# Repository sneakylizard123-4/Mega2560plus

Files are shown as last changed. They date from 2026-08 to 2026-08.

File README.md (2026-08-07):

# Mega 2560+

Mega 2560+ is an upgraded version of the Arduino Mega 2560. It keeps the same form factor and pinout as the original so it still drops into every Mega shield, but it adds an onboard sensor suite and an ESP32-S3 co-processor for WiFi, Bluetooth, and sensor reading.

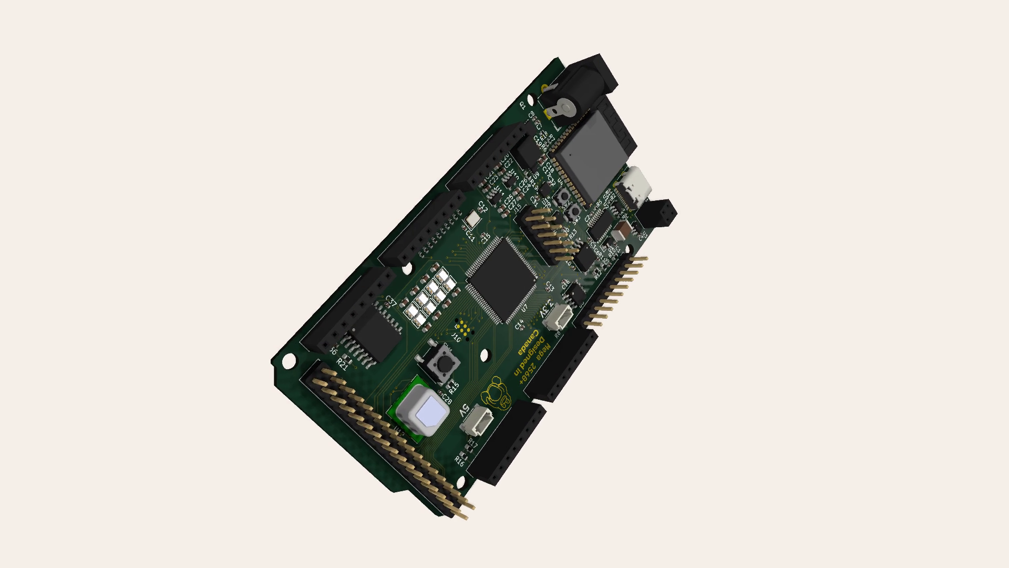
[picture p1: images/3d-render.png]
3D render


## Why I made it

I kept reaching for a Mega plus a pile of breakout boards — a CO2 sensor here, an IMU there, a WiFi module taped on somewhere. It was messy and fragile. I wanted a single board I can just drop into a project that already knows the room around it: temperature, humidity, air quality, CO2, and motion. And since everything talks to the network these days, an ESP32-S3 handles the WiFi/Bluetooth so the Mega can focus on running the actual project.

## Key Features

- ATmega2560-16A main MCU (same chip as the original Mega)
- ESP32-S3-WROOM-1U co-processor with 16MB flash / 8MB PSRAM for WiFi and Bluetooth
- Onboard sensor suite:
  - SCD41 CO2 sensor
  - BME680 temp / humidity / pressure / air quality
  - LSM6DSL 6-axis IMU
- DS3231M RTC with battery backup (CR2032)
- FM24C64C FRAM and W25Q128JVS SPI flash for storage
- USB-C with FT231XS USB-UART and ESD protection
- WS2812B-2020 addressable status LEDs
- TPS62163 buck + TLV75733 LDO power section, barrel jack or battery input with reverse polarity protection
- Drop-in Mega pinout — compatible with existing Mega shields

## Images

### PCB Layout

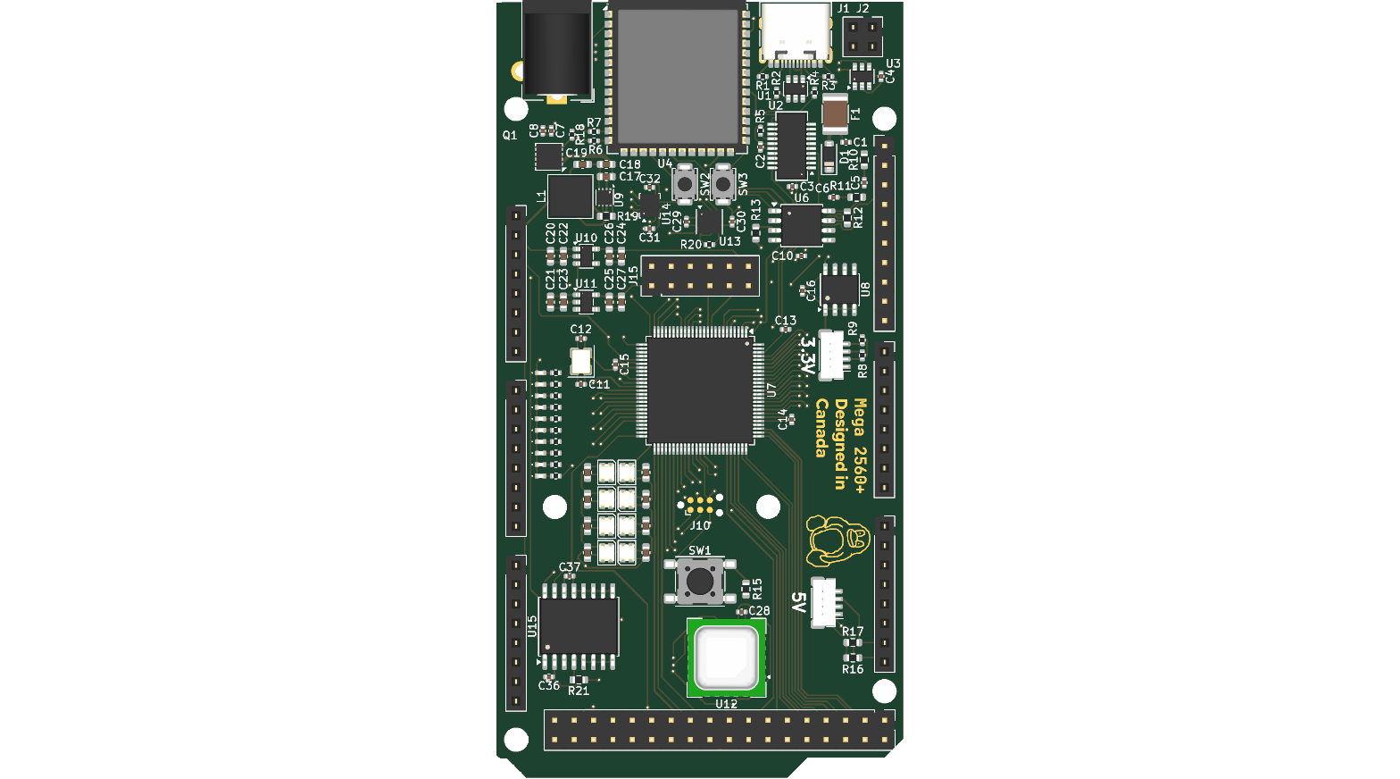
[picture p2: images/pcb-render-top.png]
PCB render


### Schematic

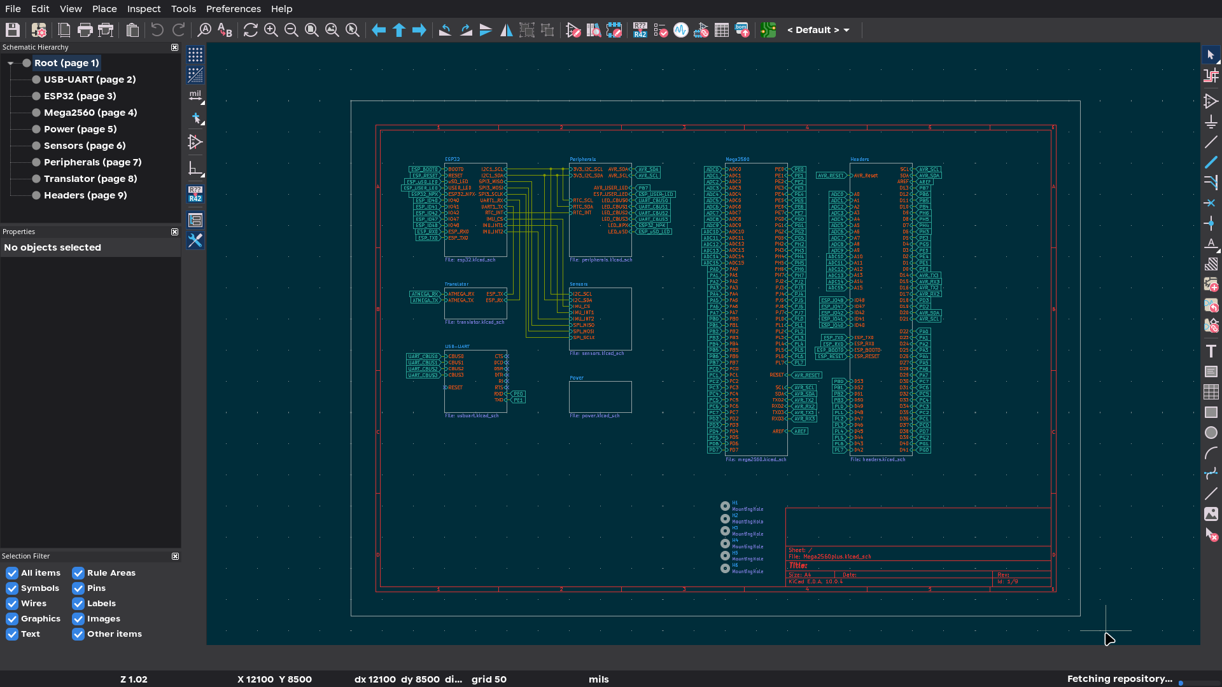
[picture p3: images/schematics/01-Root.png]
Root schematic


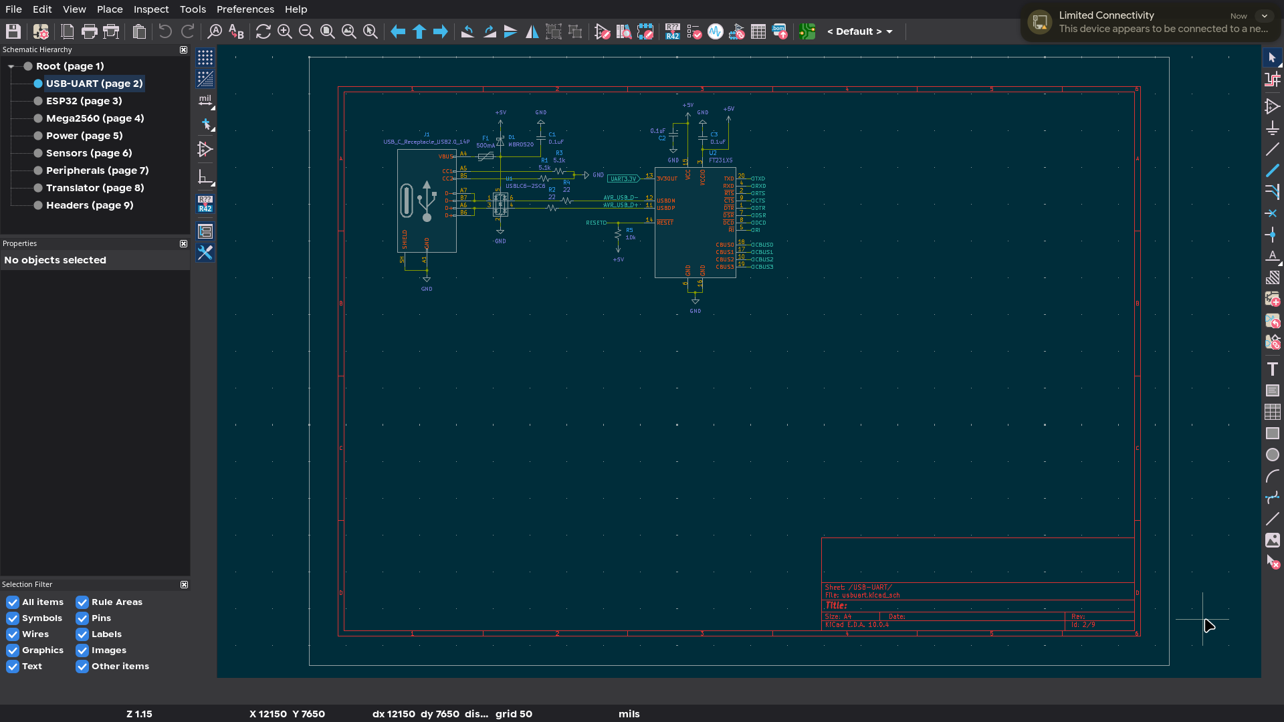
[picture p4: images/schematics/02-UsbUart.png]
USB-UART

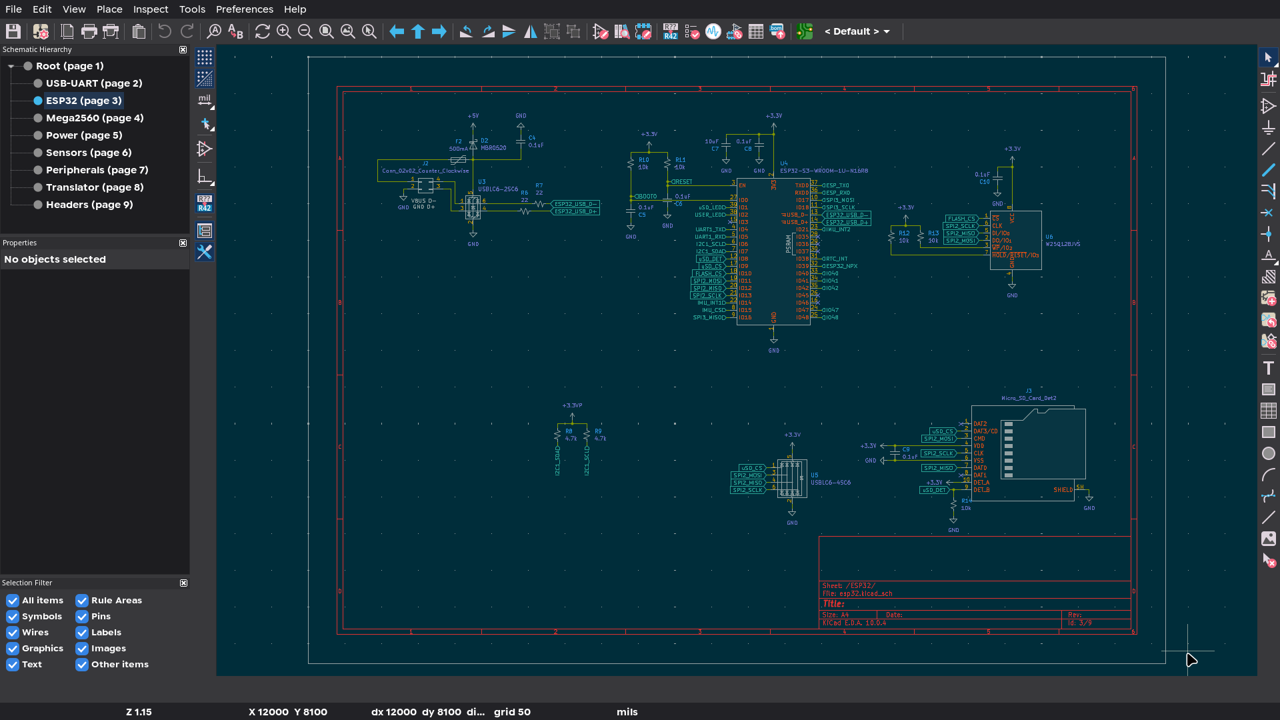
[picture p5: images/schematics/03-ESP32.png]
ESP32

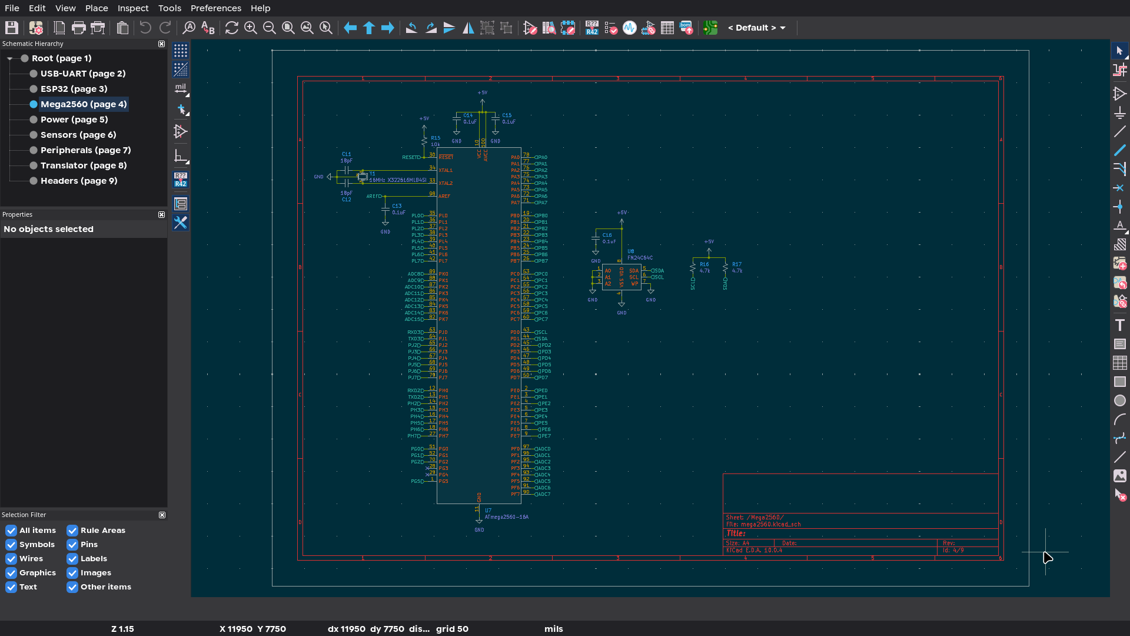
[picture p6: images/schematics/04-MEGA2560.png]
Mega 2560

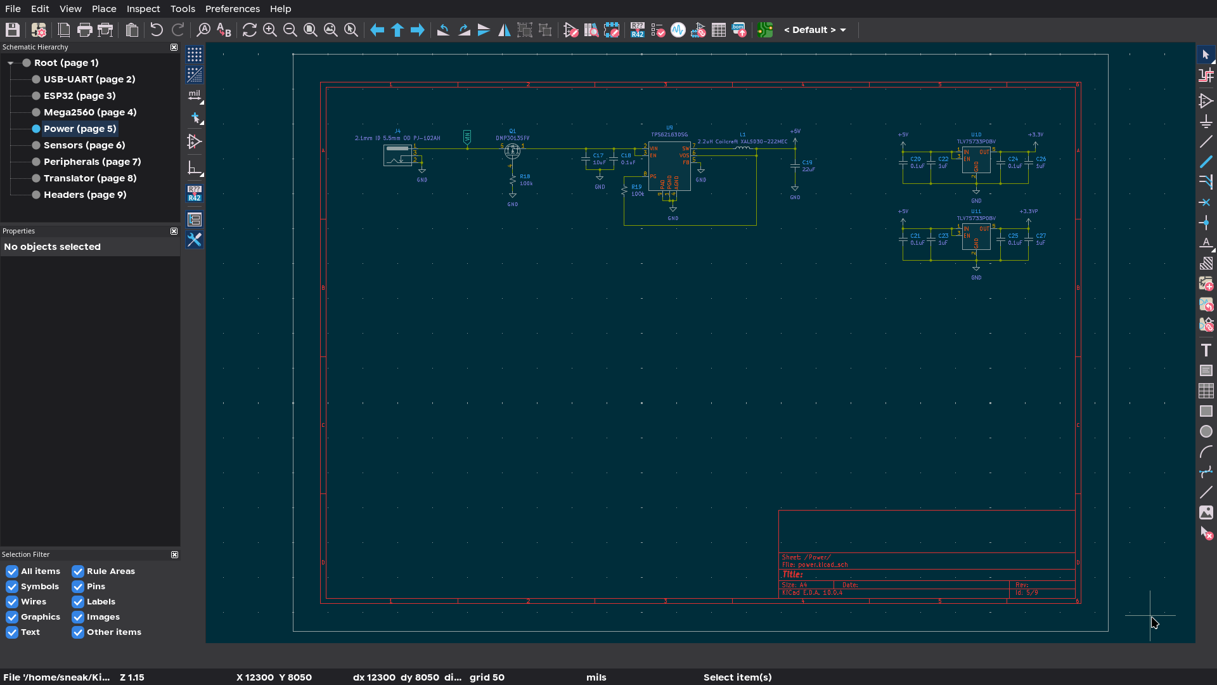
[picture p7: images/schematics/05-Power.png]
Power

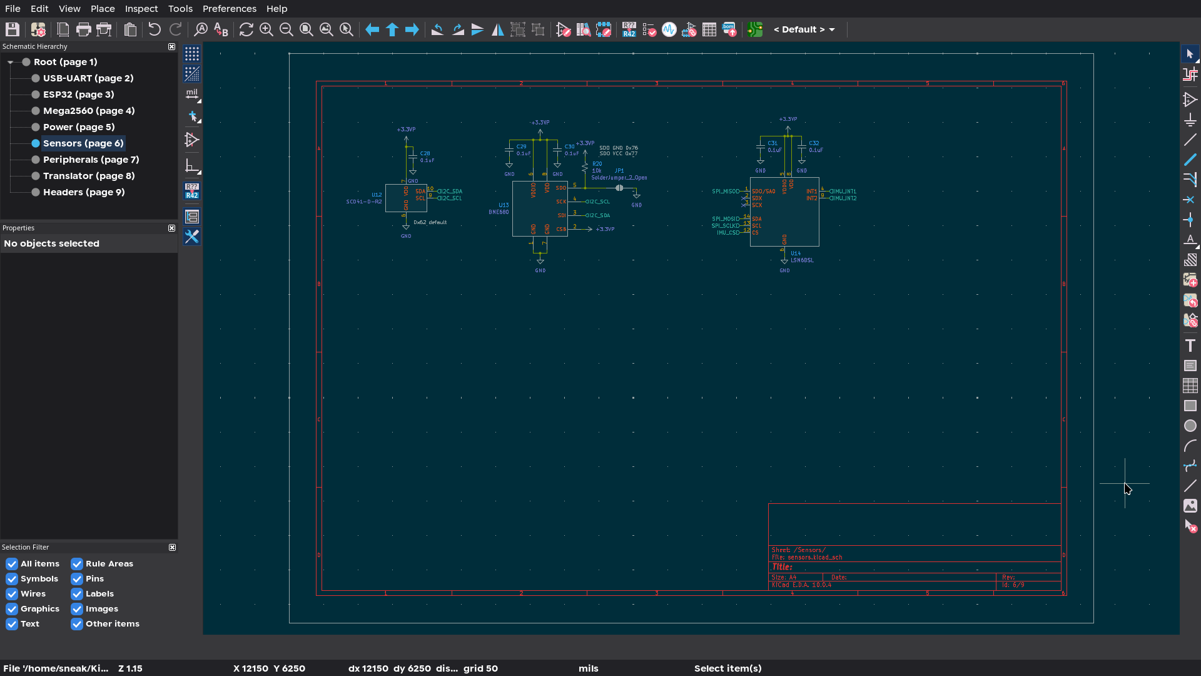
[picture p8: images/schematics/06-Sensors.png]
Sensors

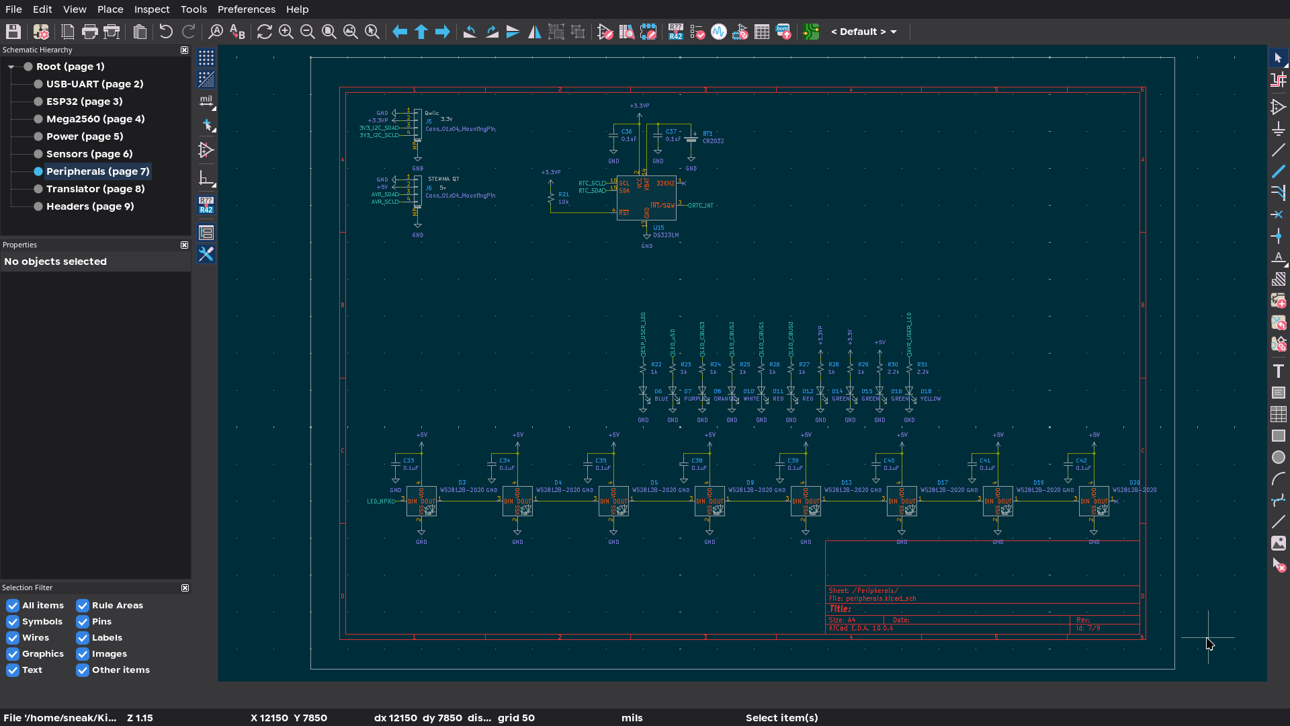
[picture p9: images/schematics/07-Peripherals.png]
Peripherals

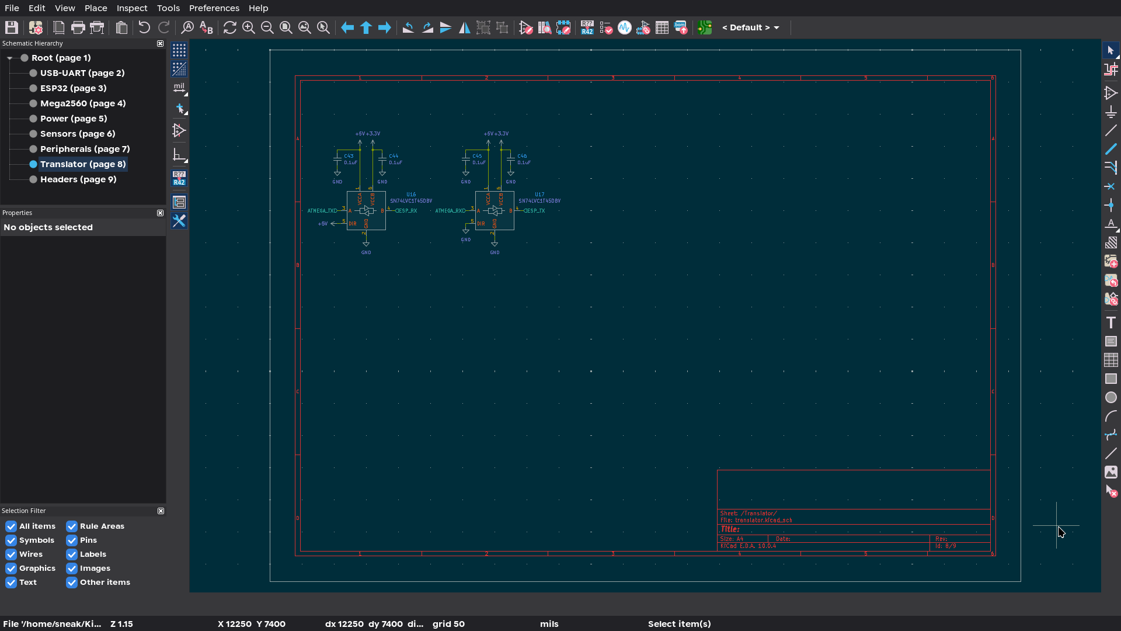
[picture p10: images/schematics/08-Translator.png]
Translator

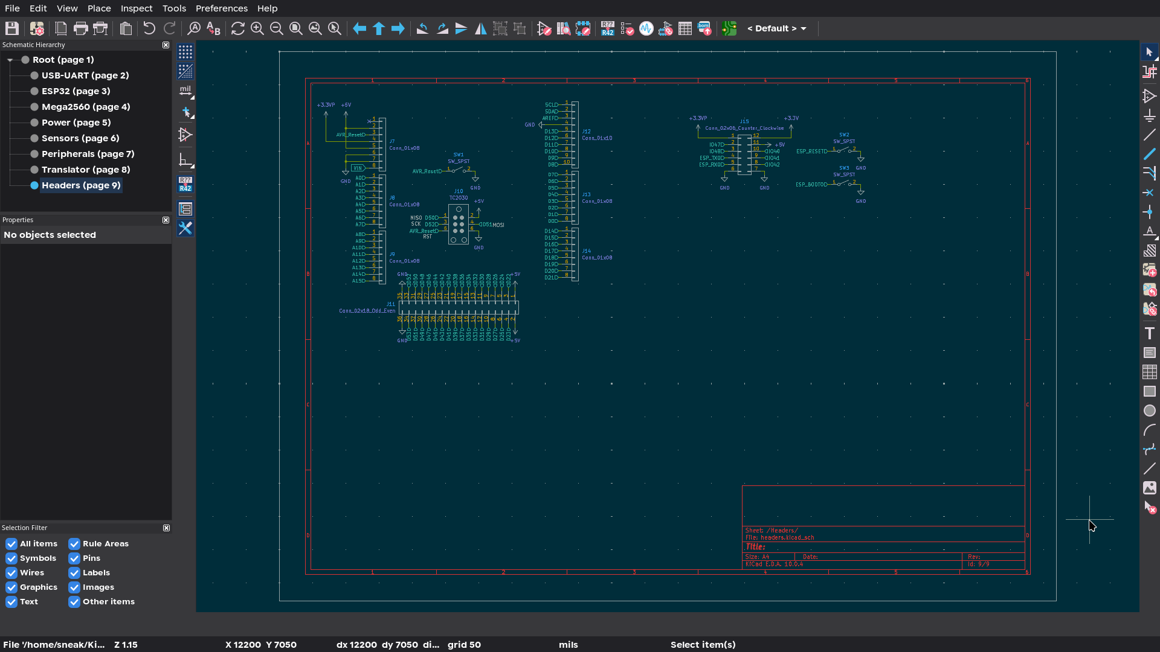
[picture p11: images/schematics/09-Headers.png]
Headers


## How to use

It's an Arduino Mega with extras. Flash it like any Mega — the ATmega2560 programs over the USB-C port. The sensors and RTC sit on the I2C bus (SCL/SDA at pins 20/21) with different addresses:

| Device | I2C Address |
|---|---|
| BME680 | 0x76 |
| SCD41 | 0x62 |
| LSM6DSL  | 0x6A |
| DS3231M  | 0x68 |

The ESP32-S3 connects to the Mega over UART (Serial1) through level translators, and handles WiFi/Bluetooth. It also reads the sensors over the same I2C bus.

## Assembly

1. Solder all SMD components, starting with the smallest packages (0402) and working up.
2. Solder the through-hole headers, connectors, and the USB-C receptacle.
3. Insert the CR2032 coin cell for RTC backup.
4. Power via USB-C or the barrel jack.

## Bill of Materials

A machine-generated `BOM.csv` lives in the repo root. Full list:

| Designators | Value | Package | Qty |
|---|---|---|-----|
| BT1 | CR2032 | Coin cell holder | 1 |
| C1-C6,C8,C10,C13-C16,C28-C32,C36,C37 | 0.1uF | 0402 | 19  |
| C7 | 10uF | 0402 | 1 |
| C9,C43-C46 | 0.1uF | 0805 | 5 |
| C11,C12 | 18pF | 0402 | 2 |
| C17 | 10uF | 0603 | 1 |
| C18,C20,C21,C24,C25,C33-C35,C38-C42 | 0.1uF | 0603 | 13  |
| C19 | 22uF | 0603 | 1 |
| C22,C23,C26,C27 | 1uF | 0603 | 4 |
| D1,D2 | MBR0520 | SOD-123 | 2 |
| D3-D5,D9,D13,D17,D19,D20 | WS2812B-2020 | PLCC-4 2.0x2.0mm | 8 |
| D6-D11,D14-D18 | Status LEDs | 0402 | 9 |
| F1,F2 | 500mA polyfuse | 1812 | 2 |
| J1 | USB-C receptacle | HRO TYPE-C-31-M-12 | 1 |
| J2 | 2x02 header | PinSocket 2.54mm | 1 |
| J3 | microSD slot | Hirose DM3D-SF | 1 |
| J4 | Barrel jack | PJ-102AH | 1 |
| J5,J6 | 1x04 JST-SH | JST SH BM04B-SRSS-TB | 2 |
| J7-J9,J13,J14 | 1x08 header | PinSocket 2.54mm | 5 |
| J11 | 2x18 header | PinHeader 2.54mm | 1 |
| J12 | 1x10 header | PinHeader 2.54mm | 1 |
| J15 | 2x06 header | PinHeader 2.54mm | 1 |
| L1 | 2.2uH | Coilcraft XAL5030 | 1 |
| Q1 | DMP3013SFV | PowerDI3333-8 | 1 |
| R1,R3 | 5.1k | 0402 | 2 |
| R2,R4,R6,R7 | 22 | 0402 | 4 |
| R5,R20 | 10k | 0402 | 2 |
| R8,R9 | 4.7k | 0402 | 2 |
| R10-R13,R15,R21 | 10k | 0603 | 6 |
| R14 | 10k | 0805 | 1 |
| R16,R17 | 4.7k | 0603 | 2 |
| R18,R19 | 100k | 0402 / 0603 | 2 |
| R22-R29 | 1k | 0402 | 8 |
| R30,R31 | 2.2k | 0402 | 2 |
| SW1 | Reset switch | PTS645Sx | 1 |
| SW2,SW3 | Buttons | TS-1088 | 2 |
| U1,U3,U5 | USBLC6 ESD protection | SOT-23-6 | 3 |
| U2 | FT231XS | SSOP-20 | 1 |
| U4 | ESP32-S3-WROOM-1U-N16R8 | ESP32-S3 module | 1 |
| U6 | W25Q128JVS | SOIC-8 | 1 |
| U7 | ATmega2560-16A | TQFP-100 | 1 |
| U8 | FM24C64C | SOIC-8 | 1 |
| U9 | TPS62163DSG | WSON-8 | 1 |
| U10,U11 | TLV75733PDBV | SOT-23-5 | 2 |
| U12 | SCD41-D-R2 | Sensirion SCD4x | 1 |
| U13 | BME680 | LGA-8 | 1 |
| U14 | LSM6DSL | LGA-14 | 1 |
| U15 | DS3231M | SOIC-16W | 1 |
| U16,U17 | SN74LVC1T45DBV | SOT-23-6 | 2 |
| Y1 | 16MHz crystal | 3225-4Pin | 1 |

**Total cost: TBD**

## Firmware

Source lives in [firmware/](firmware/) as a PlatformIO project with two environments:

| Env | Target | What it does |
|-----|---|---|
| `mega2560` | ATmega2560-16A | USB-UART (FT231XS), FM24C64C FRAM on I2C, Serial3 link to the ESP32 |
| `esp32s3` | ESP32-S3-WROOM-1U | Sensor reading (SCD41, BME680, LSM6DSL, DS3231M), SPI flash, NeoPixel status LEDs, WiFi/BT-ready |

Build with `pio run -e mega2560` and `pio run -e esp32s3`. The ESP32-S3 co-processor handles the sensors over its I2C1/SPI3 buses; the Mega keeps standard Arduino compatibility. See [firmware/README.md](firmware/README.md) for the full pin map.

## Known Issues

- None yet — board hasn't been fabbed. Expect some after the first build.

## Credits

- KiCad project files: [kicad/](kicad/)
- 3D models: Sensirion (SCD41), plus the WS2812B model referenced in the project

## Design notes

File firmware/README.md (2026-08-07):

# Mega 2560+ Firmware

PlatformIO firmware for the Mega 2560+ board. The board has two MCUs, each with its own environment:

| MCU | Env | Role |
|-----|-----|---|
| ATmega2560-16A | `mega2560` | Main MCU, drop-in Mega compatible. USB-UART via FT231XS, FM24C64C FRAM on I2C. |
| ESP32-S3-WROOM-1U-N16R8 | `esp32s3` | Co-processor. WiFi/BT, sensor suite (I2C), IMU + SPI flash (SPI). |

## Build

```bash
cd firmware
pio run -e mega2560
pio run -e esp32s3
```

Outputs: `.pio/build/mega2560/firmware.hex` and `.pio/build/esp32s3/firmware.bin`.

## Flash

```bash
# Mega 2560 (over USB via FT231XS, like any Mega)
pio run -e mega2560 -t upload

# ESP32-S3 (over native USB in download mode: hold IO0/BTN_BOOT, plug in)
pio run -e esp32s3 -t upload
```

## MCU Link

The two MCUs talk over UART through two SN74LVC1T45 level translators:

| Signal | Mega | ESP32-S3 |
|---|---|---|
| TX | Serial3 TX (D14) | UART1 RX (GPIO5) |
| RX | Serial3 RX (D15) | UART1 TX (GPIO4) |

Baud: 115200. The link is a raw byte bridge right now — Mega's `Serial` (USB) is relayed to the ESP32 `Serial` (USB CDC) and back. A structured command protocol can be layered on later.

## ESP32-S3 Pin Map

### I2C1 (sensor bus, 3.3V, 400kHz)

| Pin | Signal |
|-----|---|
| GPIO6 | SCL |
| GPIO7 | SDA |

| Device | Address |
|---|---|
| SCD41 (CO2) | 0x62 |
| BME680 | 0x76 |
| DS3231M RTC | 0x68 |

### SPI3 (IMU, 1MHz)

| Pin | Signal |
|-----|---|
| GPIO18 | SCK |
| GPIO17 | MOSI |
| GPIO16 | MISO |
| GPIO15 | CS (LSM6DSL) |

### SPI (flash, 1MHz)

| Pin | Signal |
|-----|---|
| GPIO13 | SCK |
| GPIO11 | MOSI |
| GPIO12 | MISO |
| GPIO10 | CS (W25Q128) |

### Other

| Pin | Signal |
|-----|---|
| GPIO39 | WS2812B NeoPixel data (8 LEDs) |
| GPIO2 | User LED |
| GPIO1 | microSD activity LED |
| GPIO8 | microSD detect |
| GPIO9 | microSD CS |
| GPIO14 / GPIO21 | IMU INT1 / INT2 |
| GPIO38 | RTC interrupt / SQW |
| GPIO0 | BOOT |

## Mega 2560 Pin Map

| Signal | Pin |
|---|-----|
| USB-UART | Serial0 (D0/D1) via FT231XS |
| ESP32 link | Serial3 (D14/D15) |
| FRAM (FM24C64C) | I2C, address 0x50 (D20/D21) |

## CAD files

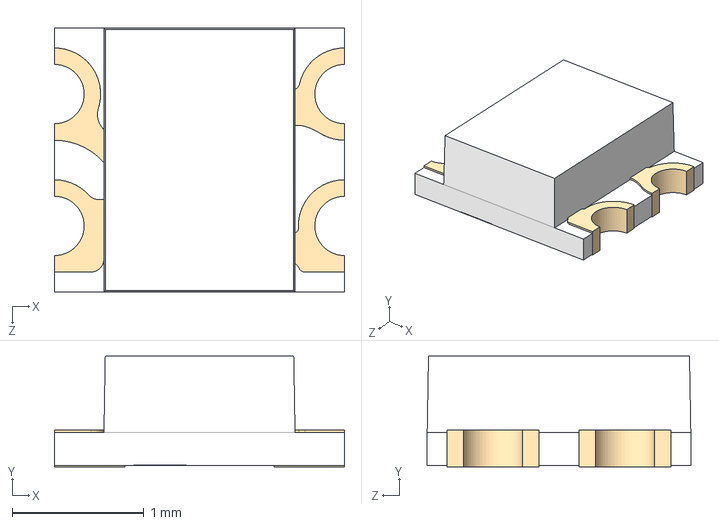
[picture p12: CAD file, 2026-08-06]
kicad/3dparts/WS2812B-2020--3DModel-STEP-269445.step
2.20 x 0.84 x 2.00 mm

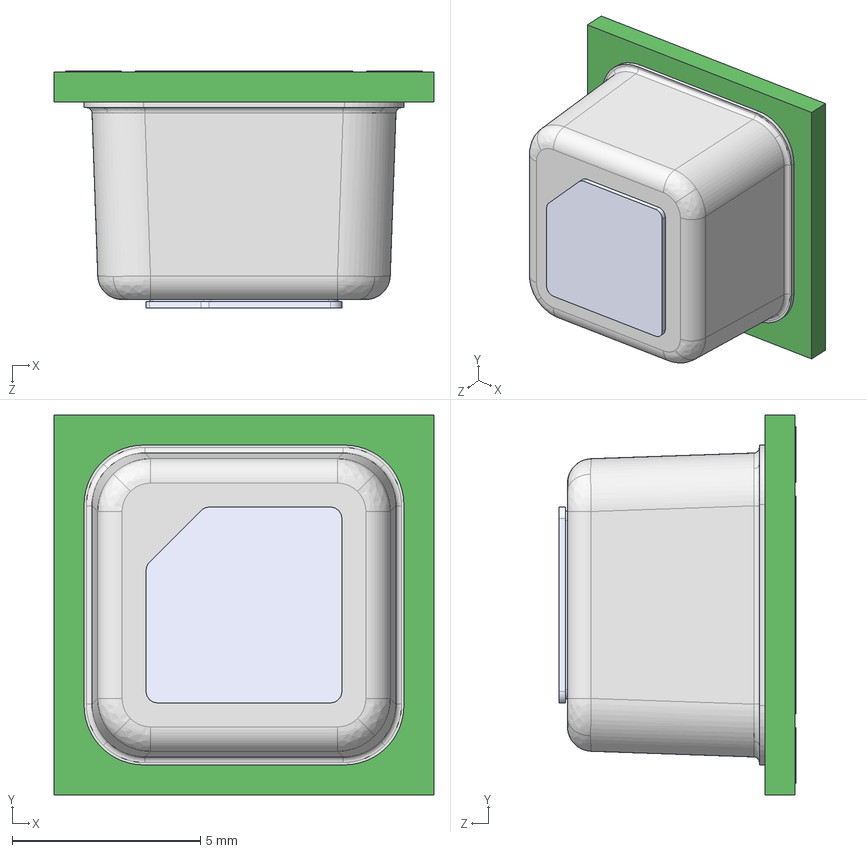
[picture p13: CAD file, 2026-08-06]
kicad/3dparts/SCD41-D-R2--3DModel-STEP-369182.step
10.1 x 10.1 x 6.31 mm

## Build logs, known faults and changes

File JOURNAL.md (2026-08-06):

---
title: "Mega 2560+"
author: sneak
description: "Upgraded Arduino Mega 2560 with an onboard sensor suite and ESP32-S3 co-processor for WiFi and Bluetooth"
created_at: "2026-08-03T00:00:00Z"
---

# August 3: project start

started the mega 2560+ project. wanted to make a beefed-up arduino mega that can sense the room around it and talk to the network without needing external modules. the idea is a mega you can just drop into projects that already knows the temp, co2, air quality, and motion, and has wifi/bluetooth built in.

main mcu is the atmega2560-16a obviously, since its the same chip the real mega uses and i know the ecosystem. added an esp32-s3 as a co-processor for wifi/bt and sensor reading, it handles the wireless stuff so the mega can focus on user code.

set up the kicad project as hierarchical sheets so each block is manageable - power, mega2560, esp32, sensors, peripherals, headers, translator, usbuart. dumped all the datasheets in and started placing the big parts.
root schematic

**Total time spent: 5 hours**

# August 3: wiring up the mega sheet

focused on the mega2560 sheet. the atmega2560 has a ton of pins and i wanted to get the core right first - decoupling on every power pin, the 16mhz crystal with load caps, reset circuit.

this sheet has the fm24c64c fram and w25q128jvs spi flash hooked up, plus the micro sd slot. grabbed an rtc too (ds3231m) so the board can keep time and date over i2c.

was a long slog of wiring. the pin mapping on the mega is 100 pins and i kept cross-referencing the schematic against the real mega pinout so headers stay drop-in compatible with existing mega shields.
mega2560 sheet

**Total time spent: 4 hours**

# August 3: sensors and esp32

did the sensors sheet - bme680 for temp/humidity/pressure/air quality, scd41 for actual co2 readings, lsm6dsl imu for motion. all on the same i2c bus with different addresses, which is nice and tidy.

the esp32-s3 sheet took the longest. it talks to the mega over uart, and needs its own flash. had to think through the power - esp32 is 3.3v, mega is 5v, so i added an sn74lvc1t45 level translator for the uart lines so they can actually talk without magic smoke.

also threw in the ws2812b-2020 leds, tiny little addressable leds that will look cool as status indicators.
esp32 sheet
sensors

**Total time spent: 5 hours**

# August 4: finished schematic, started pcb

schematic is done and passing erc. usbuart sheet with the ft231xs and usb-c connector, esd protection on the data lines. power sheet with the tps62163 buck for the main rail and tlv75733 ldo for 3.3v, barrel jack plus a battery option with the polyfuse and mbr0520 so you cant plug things in backwards and destroy everything.

started the pcb layout. this board is going to be huge - its a mega after all, keeping the same form factor so it drops into mega shields. got all the footprints assigned and started placing the big stuff. the mega pin headers take up most of the board, the fun parts go in the middle.
usbuart sheet
power

**Total time spent: 6 hours**

# August 5: 3d models and finishing the pcb

tracked down proper step models for the scd41 co2 sensor and the ws2812b leds so the 3d view isnt just a pile of boxes. the scd41 one came straight from sensirion, the ws2812b i grabbed from somewhere sketchy but it looks right.

routed the whole board. the interesting bit was keeping the antenna area of the esp32 clear and getting the switching regulator traces clean. ran drc and it passed first try which shocked me. the board is a chunky 100x53mm which is basically a mega, i love it.
pcb layout

**Total time spent: 7 hours**

# August 6: spinning render

exported a spinning render of the board to see it from all angles. satisfying seeing the whole thing come together. next up is bom export and picking lcsc parts, and probably some easter eggs on the silkscreen.
3d render

**Total time spent: 1 hour**

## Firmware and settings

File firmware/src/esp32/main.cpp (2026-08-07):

#include <Arduino.h>
#include <Wire.h>
#include <SPI.h>
#include <Adafruit_NeoPixel.h>

#define MEGA_RX 5
#define MEGA_TX 4
#define I2C_SCL 6
#define I2C_SDA 7
#define IMU_CS 15
#define IMU_SCK 18
#define IMU_MOSI 17
#define IMU_MISO 16
#define FLASH_CS 10
#define FLASH_SCK 13
#define FLASH_MOSI 11
#define FLASH_MISO 12
#define SD_CS 9
#define SD_DET 8
#define RTC_INT 38
#define NPX_PIN 39
#define NPX_COUNT 8

#define BME680_ADDR 0x76
#define SCD41_ADDR 0x62
#define DS3231_ADDR 0x68
#define LSM6DSL_ADDR 0x6A
#define FLASH_JEDEC_ID 0xEF4018

#define I2C_FREQ 400000
#define SENSOR_POLL_MS 5000

Adafruit_NeoPixel npx(NPX_COUNT, NPX_PIN, NEO_GRB + NEO_KHZ800);
SPIClass imuSpi(HSPI);

static uint8_t bcdToDec(uint8_t b)
{
    return ((b >> 4) * 10) + (b & 0x0F);
}

static bool scanAddress(uint8_t addr)
{
    Wire.beginTransmission(addr);
    return Wire.endTransmission() == 0;
}

static bool readRegI2C(uint8_t addr, uint8_t reg, uint8_t* out, size_t len)
{
    Wire.beginTransmission(addr);
    Wire.write(reg);
    if (Wire.endTransmission(false) != 0)
        return false;
    Wire.requestFrom((uint8_t)addr, (uint8_t)len);
    for (size_t i = 0; i < len && Wire.available(); i++)
        out[i] = Wire.read();
    return true;
}

static bool readBME680Id()
{
    uint8_t id = 0;
    return readRegI2C(BME680_ADDR, 0xD0, &id, 1) && id == 0x61;
}

static void readSCD41Serial(uint32_t* serial)
{
    Wire.beginTransmission(SCD41_ADDR);
    Wire.write(0x36);
    Wire.write(0x80);
    Wire.endTransmission();
    delay(10);
    uint8_t raw[9] = { 0 };
    Wire.requestFrom((uint8_t)SCD41_ADDR, (uint8_t)9);
    for (int i = 0; i < 9 && Wire.available(); i++)
        raw[i] = Wire.read();
    *serial = ((uint32_t)raw[0] << 16) | ((uint32_t)raw[1] << 8) | raw[2];
}

static uint32_t readDS3231Time()
{
    uint8_t regs[7] = { 0 };
    if (!readRegI2C(DS3231_ADDR, 0x00, regs, 7))
        return 0;
    return ((uint32_t)bcdToDec(regs[6]) << 24) | ((uint32_t)bcdToDec(regs[5]) << 16) |
           ((uint32_t)bcdToDec(regs[4]) << 8) | bcdToDec(regs[3]);
}

static bool readIMUWhoAmI()
{
    imuSpi.begin(IMU_SCK, IMU_MISO, IMU_MOSI, IMU_CS);
    imuSpi.beginTransaction(SPISettings(1000000, MSBFIRST, SPI_MODE0));
    digitalWrite(IMU_CS, LOW);
    imuSpi.transfer(0x80 | 0x0F);
    uint8_t who = imuSpi.transfer(0x00);
    digitalWrite(IMU_CS, HIGH);
    imuSpi.endTransaction();
    return who == LSM6DSL_ADDR;
}

static bool readFlashJedec(uint8_t* jedec)
{
    SPI.begin(FLASH_SCK, FLASH_MISO, FLASH_MOSI, FLASH_CS);
    SPI.beginTransaction(SPISettings(1000000, MSBFIRST, SPI_MODE0));
    digitalWrite(FLASH_CS, LOW);
    SPI.transfer(0x9F);
    for (int i = 0; i < 3; i++)
        jedec[i] = SPI.transfer(0x00);
    digitalWrite(FLASH_CS, HIGH);
    SPI.endTransaction();
    return jedec[0] == 0xEF && jedec[1] == 0x40 && jedec[2] == 0x18;
}

static void printSensorReport()
{
    uint32_t now = millis();
    uint32_t serial = 0;
    readSCD41Serial(&serial);

    Serial.println();
    Serial.println("--- Mega2560+ sensor report ---");
    Serial.print("I2C bus: ");
    Serial.print(scanAddress(BME680_ADDR) ? "BME680 " : "");
    Serial.print(scanAddress(SCD41_ADDR) ? "SCD41 " : "");
    Serial.print(scanAddress(DS3231_ADDR) ? "DS3231 " : "");
    Serial.println();
    Serial.print("BME680 id  : ");
    Serial.println(readBME680Id() ? "0x61 OK" : "missing");
    Serial.print("SCD41 ser  : ");
    Serial.println(serial, HEX);
    uint32_t dt = readDS3231Time();
    if (dt)
    {
        Serial.print("RTC (sec/date/mon/yr): ");
        Serial.println(dt, DEC);
    }
    Serial.print("LSM6DSL whoami: ");
    Serial.println(readIMUWhoAmI() ? "0x6A OK" : "missing");
    uint8_t jedec[3] = { 0 };
    bool flash = readFlashJedec(jedec);
    Serial.print("W25Q128 JEDEC: ");
    if (flash)
    {
        Serial.print("0x");
        for (int i = 0; i < 3; i++)
        {
            if (jedec[i] < 0x10)
                Serial.print("0");
            Serial.print(jedec[i], HEX);
        }
        Serial.println(" OK");
    }
    else
    {
        Serial.println("missing");
    }
    Serial.printf("uptime %us\n", now / 1000);
    Serial.println("-----------------------------");
}

void setup()
{
    Serial.begin(115200);
    Serial1.begin(115200, SERIAL_8N1, MEGA_RX, MEGA_TX);
    Wire.begin(I2C_SDA, I2C_SCL);
    Wire.setClock(I2C_FREQ);

    pinMode(IMU_CS, OUTPUT);
    digitalWrite(IMU_CS, HIGH);
    pinMode(FLASH_CS, OUTPUT);
    digitalWrite(FLASH_CS, HIGH);
    pinMode(SD_CS, OUTPUT);
    digitalWrite(SD_CS, HIGH);
    pinMode(SD_DET, INPUT_PULLUP);
    pinMode(RTC_INT, INPUT);

    npx.begin();
    npx.show();

    Serial.println("Mega2560+ ESP32 co-processor ready");
    printSensorReport();
}

void loop()
{
    static uint32_t lastPoll = 0;
    uint32_t now = millis();

    while (Serial1.available())
        Serial.write(Serial1.read());
    while (Serial.available())
        Serial1.write(Serial.read());

    if (now - lastPoll >= SENSOR_POLL_MS)
    {
        lastPoll = now;
        printSensorReport();
    }

    uint16_t hue = (now >> 2) % 360;
    for (int i = 0; i < NPX_COUNT; i++)
        npx.setPixelColor(i, npx.ColorHSV(hue + i * 45));
    npx.show();
}

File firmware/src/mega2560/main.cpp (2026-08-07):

#include <Arduino.h>
#include <Wire.h>

#define FRAM_ADDR 0x50
#define FRAM_SIZE 8192
#define ESP_SERIAL Serial3

static void framWrite(uint16_t addr, const uint8_t* data, size_t len)
{
    Wire.beginTransmission(FRAM_ADDR);
    Wire.write((uint8_t)(addr >> 8));
    Wire.write((uint8_t)(addr & 0xFF));
    Wire.write(data, len);
    Wire.endTransmission();
}

static void framRead(uint16_t addr, uint8_t* data, size_t len)
{
    Wire.beginTransmission(FRAM_ADDR);
    Wire.write((uint8_t)(addr >> 8));
    Wire.write((uint8_t)(addr & 0xFF));
    Wire.endTransmission(false);
    Wire.requestFrom((uint8_t)FRAM_ADDR, (uint8_t)len);
    for (size_t i = 0; i < len && Wire.available(); i++)
        data[i] = Wire.read();
}

void setup()
{
    Serial.begin(115200);
    ESP_SERIAL.begin(115200);
    Wire.begin();
    Wire.setClock(400000);

    const uint8_t magic[] = { 'M', '2', '5', '6', '0' };
    uint8_t check[sizeof(magic)] = { 0 };
    framWrite(0x0000, magic, sizeof(magic));
    framRead(0x0000, check, sizeof(check));

    Serial.println("Mega2560+ ready");
    Serial.print("FRAM check: ");
    Serial.println(memcmp(magic, check, sizeof(magic)) == 0 ? "OK" : "FAIL");
}

void loop()
{
    while (Serial.available())
        ESP_SERIAL.write(Serial.read());
    while (ESP_SERIAL.available())
        Serial.write(ESP_SERIAL.read());
}

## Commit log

2026-08-04 finished adding nets to mega2560 sheet
    [Mega2560plus.kicad_sch, esp32.kicad_sch, headers.kicad_sch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]
2026-08-04 exit kicad
2026-08-05 finished schematic and start pcb
    [Mega2560plus.kicad_pcb, Mega2560plus.kicad_sch, esp32.kicad_sch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]
2026-08-06 add 3d models
    [SCD41-D-R2--3DModel-STEP-369182.step, WS2812B-2020--3DModel-STEP-269445.step]
2026-08-06 finish pcb
    [Mega2560plus.kicad_pcb, Mega2560plus.kicad_sch, esp32.kicad_sch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]
2026-08-06 add spinning render
    [.Mega2560plus.spinrender-src.kicad_pcb, .Mega2560plus.spinrender-tmp.kicad_pcb, Mega2560plus.kicad_pcb]
2026-08-06 fix silkscreen
    [Mega2560plus.kicad_pcb, Mega2560plus.kicad_sch, esp32.kicad_sch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]
2026-08-07 start bom and add firmware
    [BOM.csv]
